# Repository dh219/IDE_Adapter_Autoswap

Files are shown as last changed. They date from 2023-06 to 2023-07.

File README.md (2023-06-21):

# Auto-byteswitching IDE Adapter for the Atari Falcon

44-pin 2mm pitch IDE host to two device adapter supporting cable select with automatic physical byte swapping

## Atari Falcon

This adapter is intended for use in my Atari Falcon which has an 44-pin 2mm-pitch IDE connection soldered to the board with only one connector for a hard disc.

This allows two discs to be added to the Falcon, if they support running in master/slave configuration, either via jumpers on the discs, or via cable select, which this board supports.

## Byte Swap

This board also automatically swaps data bytes which a suitable hard disc driver on the atari can make use of for faster interoperability with modern machines.

## Youtube

My video demonstrating this and assembing it will be found here

## PCBWay

I have A PCBWay Profile where you may find & order this project when released: https://www.pcbway.com/project/member/?bmbno=2C89C44C-EDF4-43

Copyright 2023 D Henderson, released under the terms of the GPLv2

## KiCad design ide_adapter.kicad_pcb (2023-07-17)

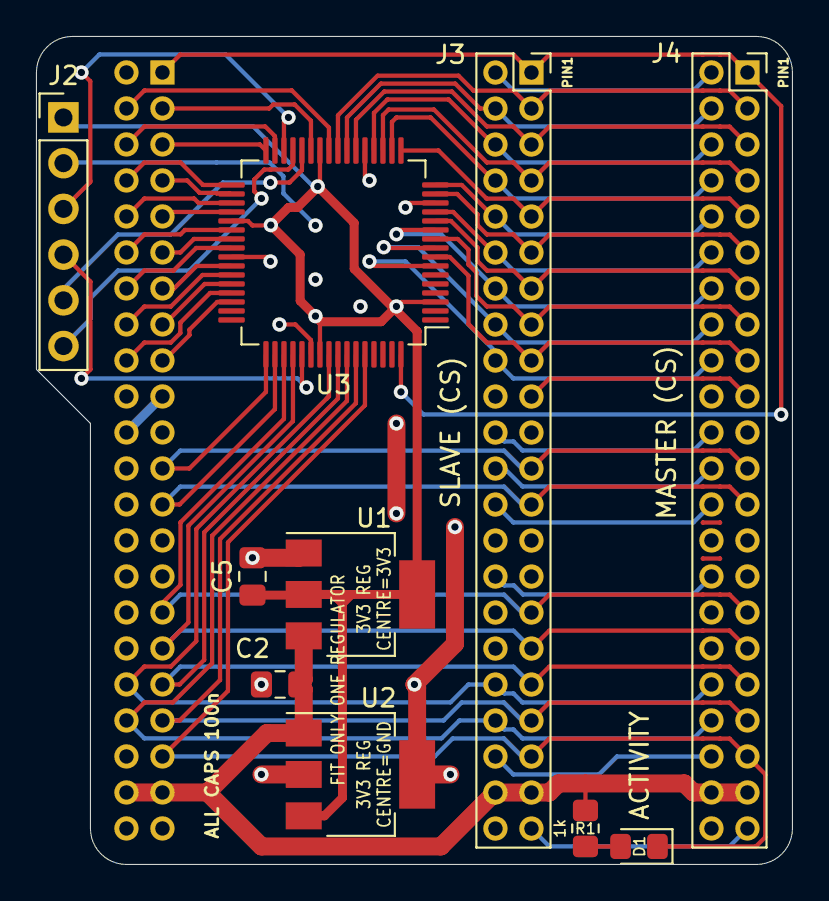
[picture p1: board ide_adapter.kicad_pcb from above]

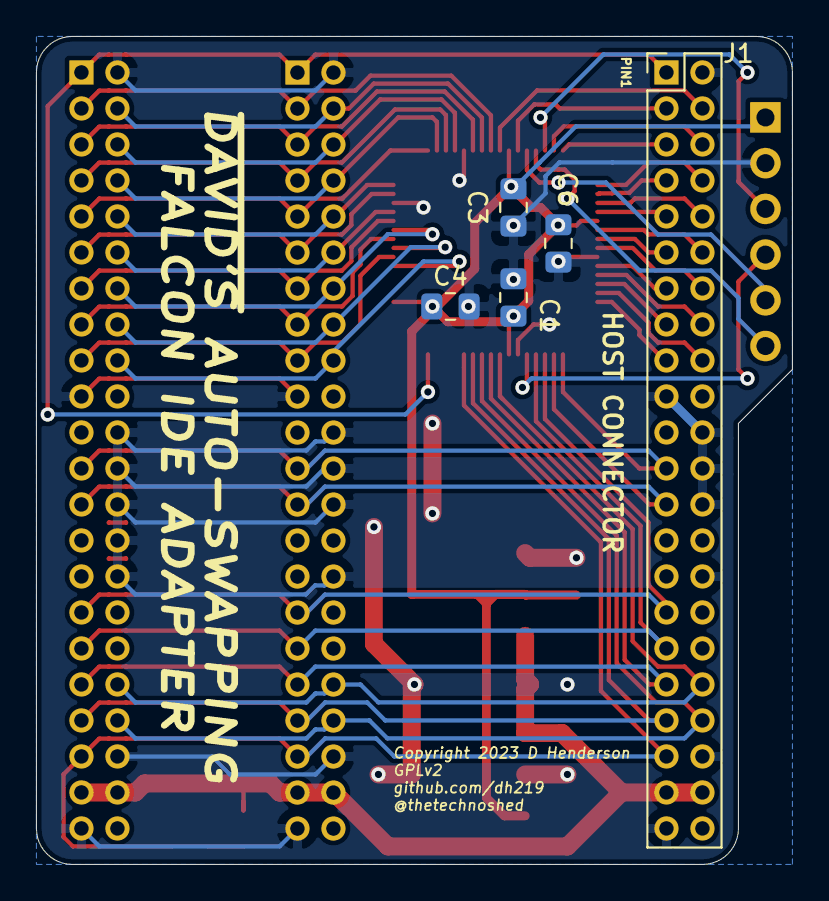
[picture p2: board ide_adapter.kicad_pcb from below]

Board: 2 copper layers, 42.0 x 46.0 mm, 15 parts (5 on the bottom side), 50 nets.

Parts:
C1, C2, C3, C4, C5, C6: 100n; C_0805_2012Metric_Pad1.18x1.45mm_HandSolder
D1: LED; LED_0805_2012Metric_Pad1.15x1.40mm_HandSolder
J1: PATA-44_Host; PinHeader_2x22_P2.00mm_Vertical
J2: Conn_01x06_Male; PinHeader_1x06_P2.54mm_Vertical
J3, J4: PATA-44_Drive; PinSocket_2x22_P2.00mm_Vertical
R1: 1k; R_0805_2012Metric_Pad1.20x1.40mm_HandSolder
U1: LM1117-3.3; SOT-223-3_TabPin2
U2: LT1129-3.3_SOT223; SOT-223-3_TabPin2
U3: XC9572XL-VQ64; TQFP-64_10x10mm_P0.5mm

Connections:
+3V3: C1.1, C3.1, C4.1, C5.1, C6.1, J2.1, U1.2, U2.3, U3.3, U3.26, U3.37, U3.55
+5V: C2.1, J1.41, J1.42, J3.41, J3.42, J4.41, J4.42, R1.2, U1.3, U2.1
/D0: J1.17, U3.46
/D1: J1.15, U3.44
/D2: J1.13, U3.42
/D3: J1.11, U3.39
/D4: J1.9, U3.36
/D5: J1.7, U3.34
/D6: J1.5, U3.32
/D7: J1.3, U3.27
/D8: J1.4, U3.25
/D9: J1.6, U3.31
/D10: J1.8, U3.33
/D11: J1.10, U3.35
/D12: J1.12, U3.38
/D13: J1.14, U3.40
/D14: J1.16, U3.43
/D15: J1.18, U3.45
/DA0: J1.35, J3.35, J4.35, U3.57
/DA1: J1.33, J3.33, J4.33, U3.52
/DA2: J1.36, J3.36, J4.36, U3.56
/DD0: J3.17, J4.17, U3.8
/DD1: J3.15, J4.15, U3.10
/DD2: J3.13, J4.13, U3.12
/DD3: J3.11, J4.11, U3.15
/DD4: J3.9, J4.9, U3.17
/DD5: J3.7, J4.7, U3.19
/DD6: J3.5, J4.5, U3.22
/DD7: J3.3, J4.3, U3.24
/DD8: J3.4, J4.4, U3.23
/DD9: J3.6, J4.6, U3.20
/DD10: J3.8, J4.8, U3.18
/DD11: J3.10, J4.10, U3.16
/DD12: J3.12, J4.12, U3.13
/DD13: J3.14, J4.14, U3.11
/DD14: J3.16, J4.16, U3.9
/DD15: J3.18, J4.18, U3.7
/INTRQ: J1.31, J3.31, J4.31, U3.51
/TCK: J2.3, U3.30
/TDI: J2.5, U3.28
/TDO: J2.4, U3.53
/TMS: J2.6, U3.29
/~CS0: J1.37, J3.37, J4.37, U3.59
/~CS1: J1.38, J3.38, J4.38, U3.58
/~DIOR: J1.25, J3.25, J4.25, U3.50
/~DIOW: J1.23, J3.23, J4.23, U3.49
/~LED: D1.1, J1.39, J3.39, J4.39, U3.60
/~RESET: J1.1, J3.1, J4.1, U3.64
GND: C1.2, C2.2, C3.2, C4.2, C5.2, C6.2, J1.2, J1.19, J1.22, J1.24, J1.26, J1.30, J1.40, J1.43, J2.2, J3.2, J3.19, J3.22, J3.24, J3.26, J3.30, J3.40, J3.43, J4.2, J4.19, J4.22, J4.24, J4.26, J4.28, J4.30, J4.40, J4.43, U1.1, U2.2, U3.14, U3.21, U3.41, U3.54
unnamed: D1.2, R1.1

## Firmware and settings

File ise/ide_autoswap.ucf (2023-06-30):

#NET "LDS" LOC = "P27" ;
#NET "FC<1>" LOC = "P25" ;

NET D<15> LOC = "P45" ;
NET D<14> LOC = "P43" ;
NET D<13> LOC = "P40" ;
NET D<12> LOC = "P38" ;
NET D<11> LOC = "P35" ;
NET D<10> LOC = "P33" ;
NET D<9> LOC = "P31" ;
NET D<8> LOC = "P25" ;
NET D<7> LOC = "P27" ;
NET D<6> LOC = "P32" ;
NET D<5> LOC = "P34" ;
NET D<4> LOC = "P36" ;
NET D<3> LOC = "P39" ;
NET D<2> LOC = "P42" ;
NET D<1> LOC = "P44" ;
NET D<0> LOC = "P46" ;

NET DD<15> LOC = "P7" ;
NET DD<14> LOC = "P9" ;
NET DD<13> LOC = "P11" ;
NET DD<12> LOC = "P13" ;
NET DD<11> LOC = "P16" ;
NET DD<10> LOC = "P18" ;
NET DD<9> LOC = "P20" ;
NET DD<8> LOC = "P23" ;
NET DD<7> LOC = "P24" ;
NET DD<6> LOC = "P22" ;
NET DD<5> LOC = "P19" ;
NET DD<4> LOC = "P17" ;
NET DD<3> LOC = "P15" ;
NET DD<2> LOC = "P12" ;
NET DD<1> LOC = "P10" ;
NET DD<0> LOC = "P8" ;


NET _CS<1> LOC = "P58" ;
NET _CS<0> LOC = "P59" ;
NET _LED LOC = "P60" ;
NET _RESET LOC = "P64" ;
	
NET _DIOW LOC = "P49" ;
NET _DIOR LOC = "P50" ;
NET INTRQ LOC = "P51" ;

NET DA<0> LOC = "P57" ;
NET DA<1> LOC = "P56" ;
NET DA<2> LOC = "P52" ;

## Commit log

2023-06-21 First attempt at an auto-swapping ide interface.
    [ide_adapter.kicad_pcb, ide_adapter.sch]
2023-06-21 Version 1 as ordered
    [ide_adapter.kicad_pcb, ide_adapter.sch]
2023-07-11 Adding silkscreen for release.
    [ide_adapter.kicad_pcb]
